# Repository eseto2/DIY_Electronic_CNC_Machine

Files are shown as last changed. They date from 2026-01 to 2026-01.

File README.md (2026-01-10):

# Introduction to DIY 3D Printed CNC Machine

## 🛠 Project Overview
This project documents the design and assembly of a low-cost, fully functional CNC machine built using **3D printed parts**, **aluminum profiles**, and **standard electronics**. It is capable of milling materials ranging from wood and MDF to acrylic and aluminum.

## ⚙️ Hardware & Electronics
The machine relies on accessible components. Below is a summary of the key parts required:

| Part | What it looks like | Amount needed |
| --- | --- | --- |
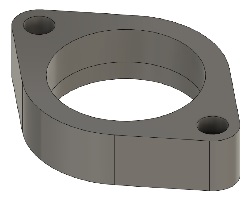
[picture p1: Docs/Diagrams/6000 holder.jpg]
6000 holder
| [6000 holder](6000%20holder.stl) |  | 3 |
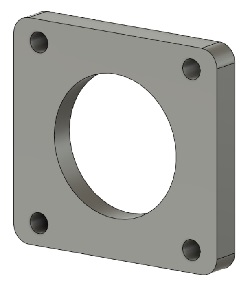
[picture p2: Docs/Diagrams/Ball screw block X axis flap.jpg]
Ball screw block X axis flap
| [Ball screw block X axis flap](Ball%20screw%20block%20X%20axis%20flap.stl) |  | 1
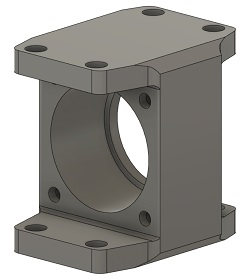
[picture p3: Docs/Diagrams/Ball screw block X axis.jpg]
Ball screw block X axis
| [Ball screw block X axis](Ball%20screw%20block%20X%20axis.stl) |  | 1
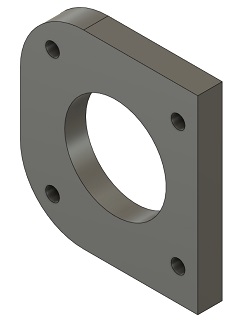
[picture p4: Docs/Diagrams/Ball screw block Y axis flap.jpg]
Ball screw block Y axis flap
| [Ball screw block Y axis flap](Ball%20screw%20block%20X%20axis%20flap.stl) |  | 2
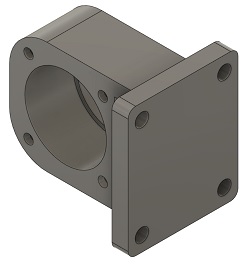
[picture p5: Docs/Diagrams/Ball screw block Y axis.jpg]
Ball screw block Y axis
| [Ball screw block Y axis](Ball%20screw%20block%20Y%20axis.stl) |  | 2
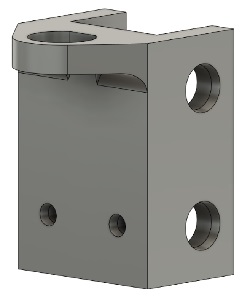
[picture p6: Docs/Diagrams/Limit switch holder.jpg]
Limit switch holder
| [Limit switch holder](Limit%20switch%20holder.stl) |  | 3
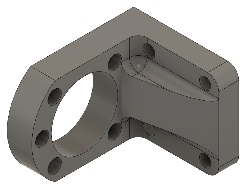
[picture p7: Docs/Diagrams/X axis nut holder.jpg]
X axis nut holder
| [X axis nut holder](X%20axis%20nut%20holder.stl) |  | 1
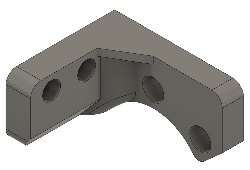
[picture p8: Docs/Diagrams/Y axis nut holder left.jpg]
Y axis nut holder left
| [Y axis nut holder left](Y%20axis%20nut%20holder%20left.stl) |  | 1
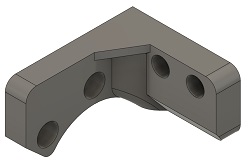
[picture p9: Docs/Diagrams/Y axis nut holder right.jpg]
Y axis nut holder right
| [Y axis nut holder right](Y%20axis%20nut%20holder%20right.stl) |  | 1
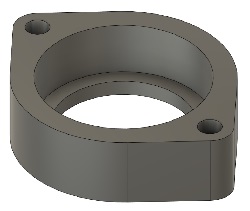
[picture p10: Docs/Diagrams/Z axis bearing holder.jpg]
Z axis bearing holder
| [Z axis bearing holder](Z%20axis%20bearing%20holder.stl) |  | 1
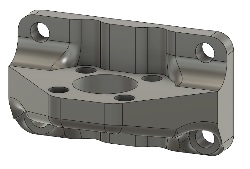
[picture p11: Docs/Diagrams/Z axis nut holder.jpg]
Z axis nut holder
| [Z axis nut holder](Z%20axis%20nut%20holder.stl) |  | 1

### Mechanical
- **Frame:** 20x20mm Aluminum Profiles (various lengths).
- **Linear Motion:** 12mm rods, Lead screws (725mm, 515mm, 160mm), and linear bearings.
- **Drive System:** GT2 timing belts and pulleys (16T & 20T).

### Electronics
- **Controller:** Arduino Uno with CNC Shield.
- **Motors:** 4x Nema 17 Stepper Motors (1.7A).
- **Drivers:** A4988 or DRV8825 stepper drivers.
- **Spindle:** 500W Spindle or 775 DC Motor.
- **Power:** 12V Power Supply (6A recommended).

## 🖨️ 3D Printing Instructions
All structural brackets and mounts are 3D printed.
- **Material:** PETG is recommended for flexibility and durability, though PLA is sufficient.
- **Infill:** 20% - 50%.
- **Perimeters:** Minimum of 5 layers (Crucial for part strength).
- **Supports:** Required for specific orientations.

## 💻 Software & Firmware
1.  **Firmware:** **GRBL** installed on the Arduino Uno.
    - *Configuration:* Set steps/mm ($100=400, etc.) via console commands.
2.  **Control Software:** **CNCjs** is recommended for sending G-code. It is open-source, cross-platform (Windows/Mac/Linux/Raspberry Pi), and has a user-friendly interface.

## 📐 Milling Settings (Reference)
Recommended starting points for different materials:

| Material | Feed Rate | Depth of Cut | Notes |
| :--- | :--- | :--- | :--- |
| **Wood / MDF** | 800 mm/min | 3 mm | Adaptive clearing recommended |
| **Acrylic** | 500 mm/min | 1 mm |
| **Aluminum** | 800 mm/min | 0.2 mm | Spindle at full speed |

## ⚠️ Safety
- **Eye Protection:** Always wear safety glasses to protect against flying chips.
- **Emergency Stop:** Install a physical kill switch or keep the software stop button accessible.
- **Hearing Protection:** Recommended for long milling sessions.
## Videos

[3D CNC Final test]

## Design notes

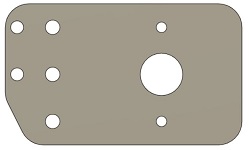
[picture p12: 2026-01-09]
Docs/Diagrams/Screw Support Left.jpg

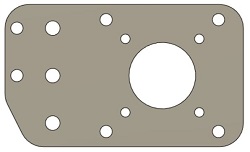
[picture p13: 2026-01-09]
Docs/Diagrams/Motor Support Left.jpg

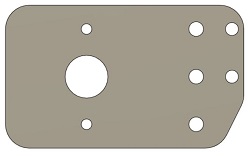
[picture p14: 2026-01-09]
Docs/Diagrams/Screw Support Right.jpg

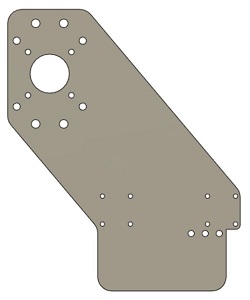
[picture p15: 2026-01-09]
Docs/Diagrams/Y Axis Left.jpg

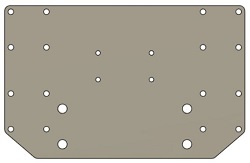
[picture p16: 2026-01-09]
Docs/Diagrams/500W Spindle Plate.jpg

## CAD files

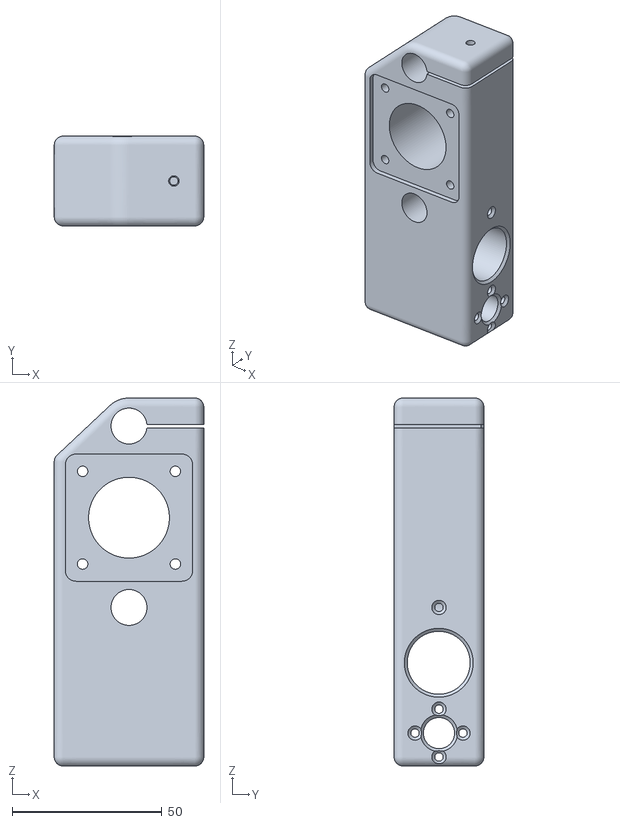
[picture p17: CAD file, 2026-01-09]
Axis_Carriage/x_axis_carriage_right.stl
50.0 x 30.0 x 123.0

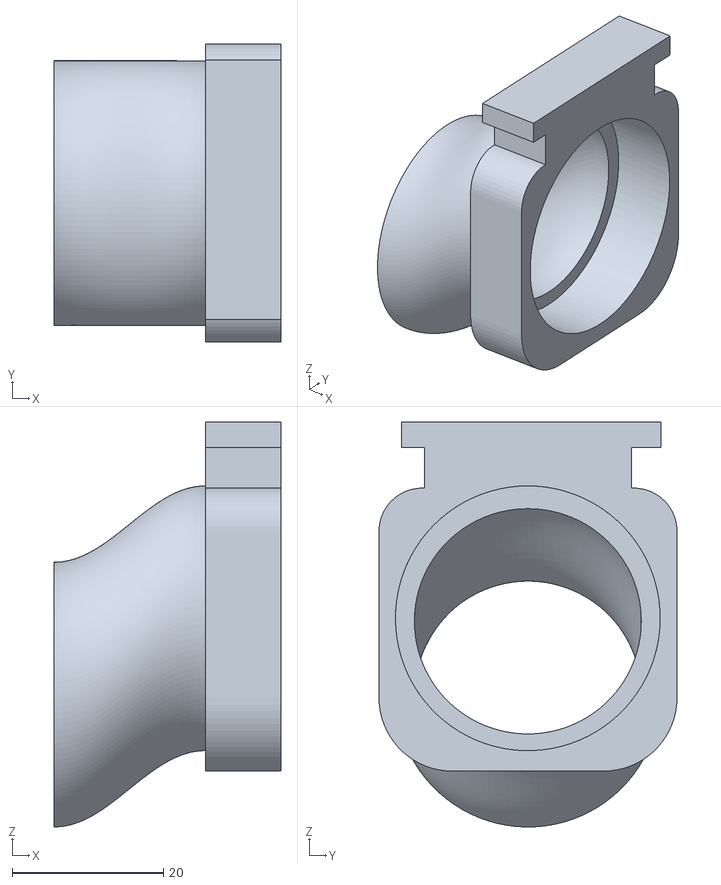
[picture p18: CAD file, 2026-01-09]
Electronics_Covers/hose connector v3.stl
30.0 x 39.4 x 53.5

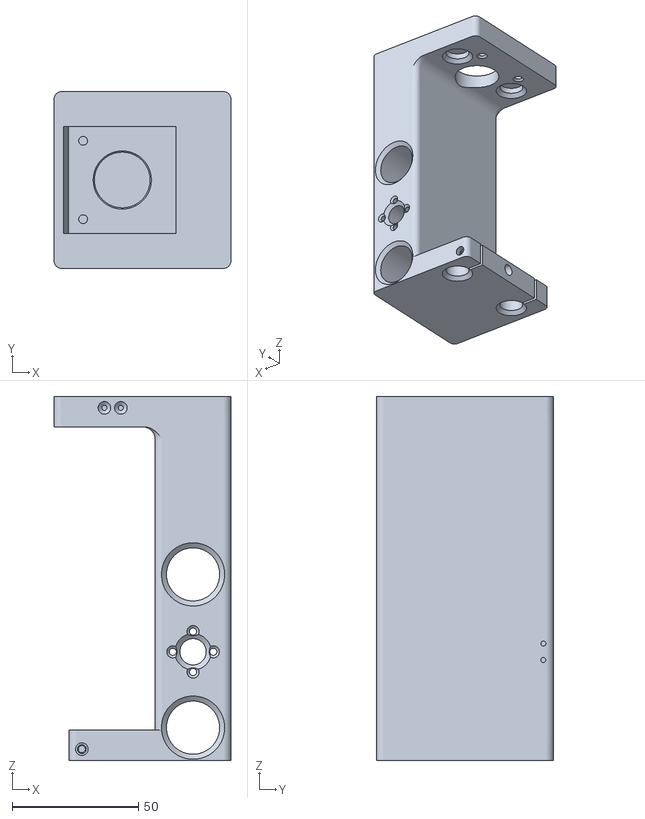
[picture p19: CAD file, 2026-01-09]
spindle_carriage.stl
70.0 x 70.0 x 144.0

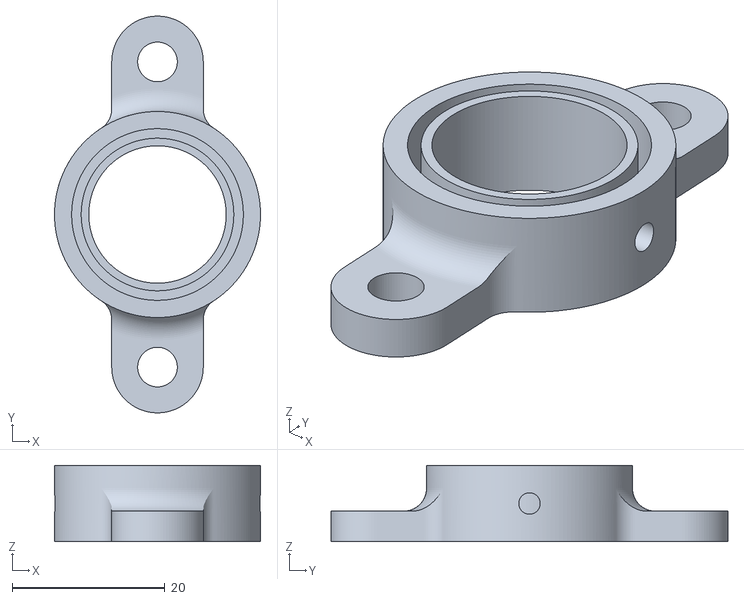
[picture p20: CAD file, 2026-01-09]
1.stl
27.0 x 52.0 x 10.0

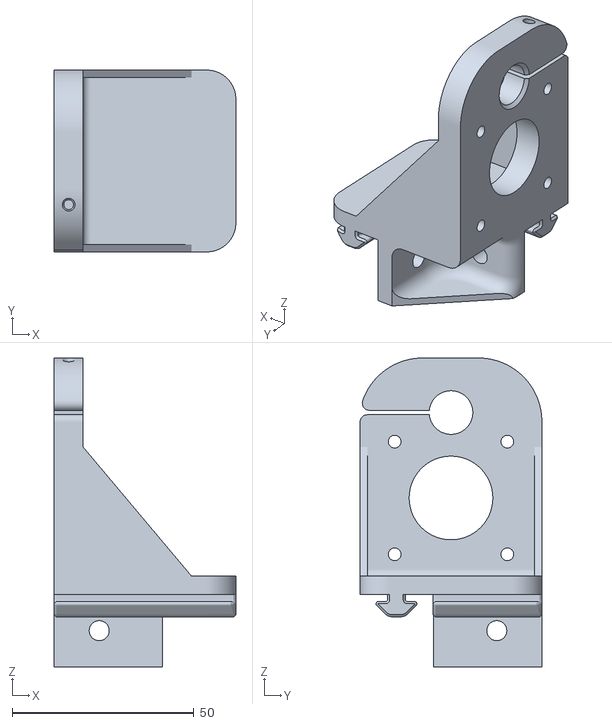
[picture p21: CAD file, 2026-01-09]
Axis_Carriage/y_axis_motor_holder_right.stl
50.0 x 50.0 x 85.0

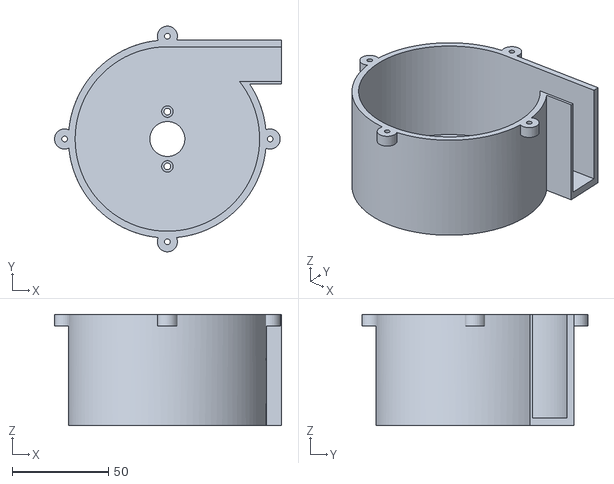
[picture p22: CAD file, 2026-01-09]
Electronics_Covers/DUst COllector Motor mount v7.stl
118.1 x 117.5 x 58.0

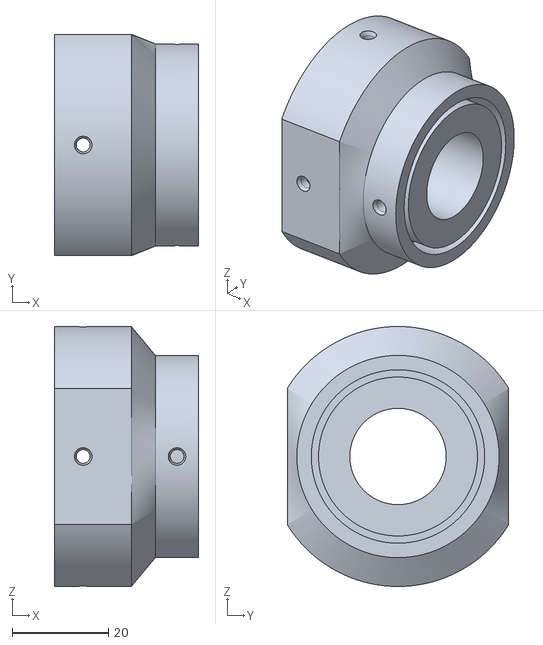
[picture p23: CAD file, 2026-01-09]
2.stl
30.0 x 46.0 x 54.0

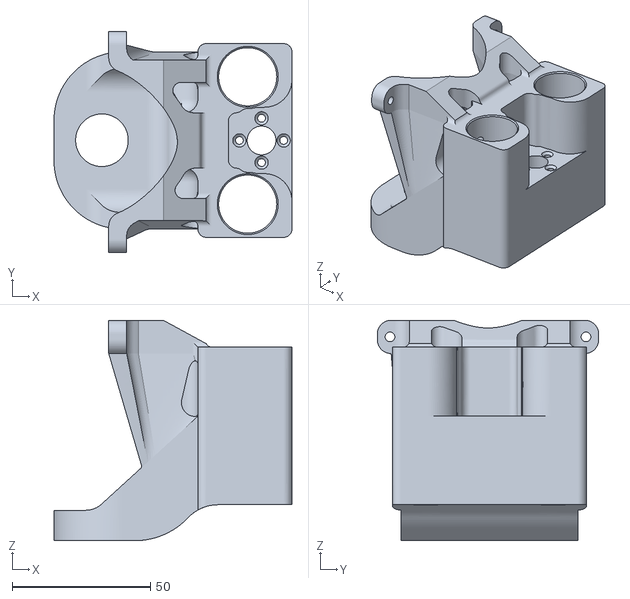
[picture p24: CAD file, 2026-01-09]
Axis_Carriage/z_axis_carriage.stl
86.0 x 80.0 x 79.6

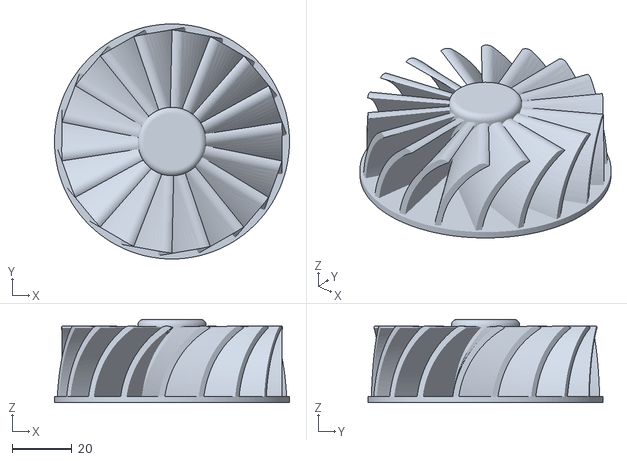
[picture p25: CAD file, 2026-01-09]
Electronics_Covers/Impeller change dirx v2.stl
79.0 x 79.0 x 28.0

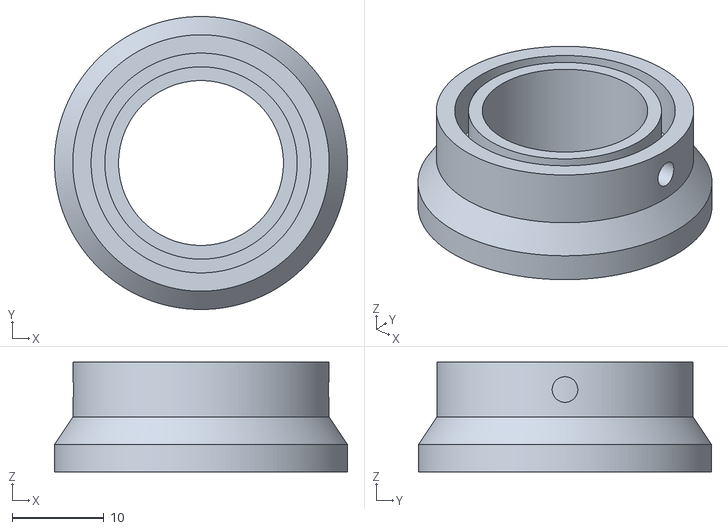
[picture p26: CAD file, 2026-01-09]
4.stl
32.0 x 32.0 x 12.0

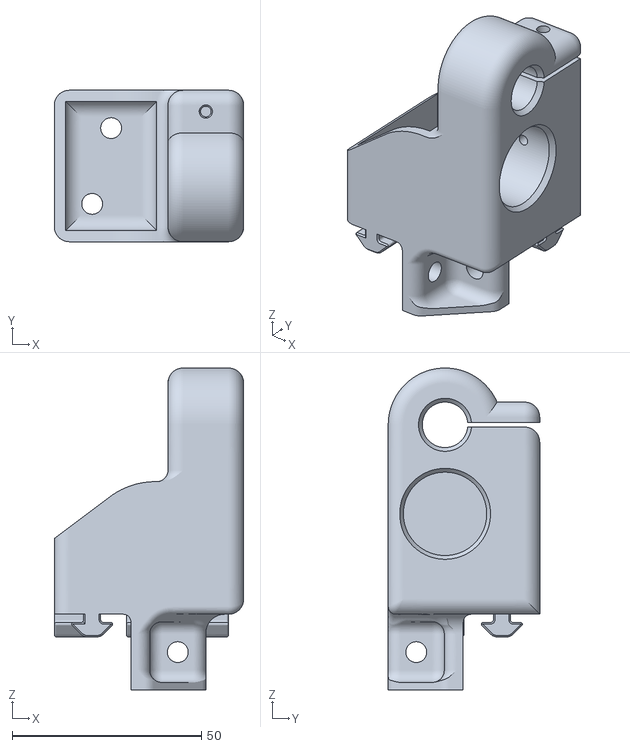
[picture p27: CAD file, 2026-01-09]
Axis_Carriage/y_axis_rod_holder_left.stl
50.0 x 40.0 x 85.0

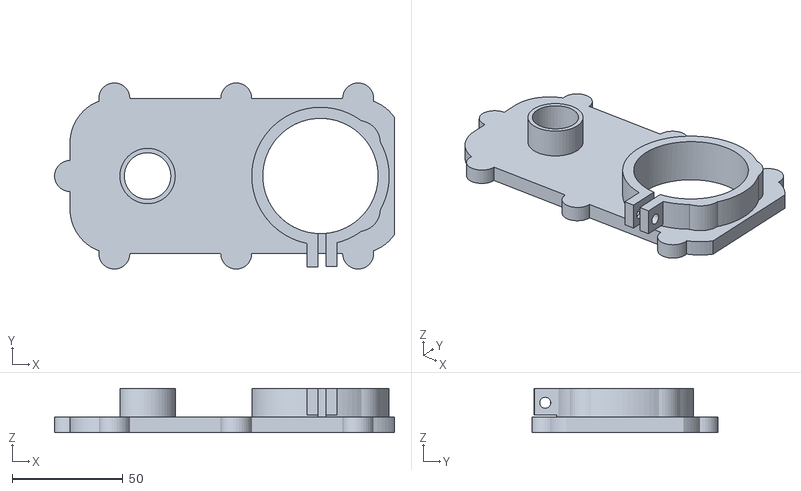
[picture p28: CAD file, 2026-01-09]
Electronics_Covers/Dust collector top v4.stl
153.4 x 84.0 x 20.0

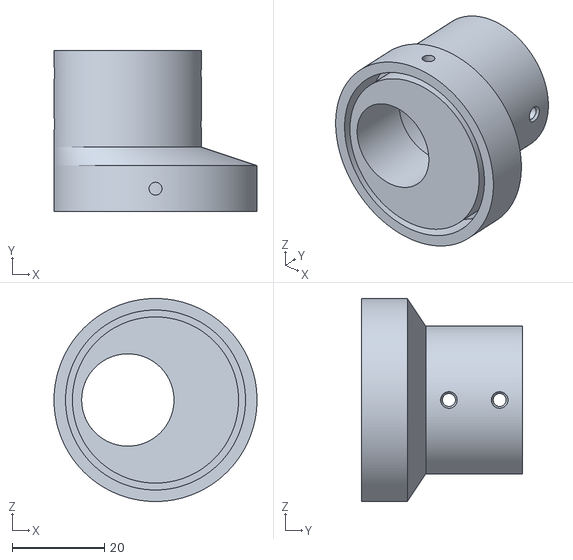
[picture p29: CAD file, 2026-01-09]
3.stl
44.0 x 35.0 x 44.0

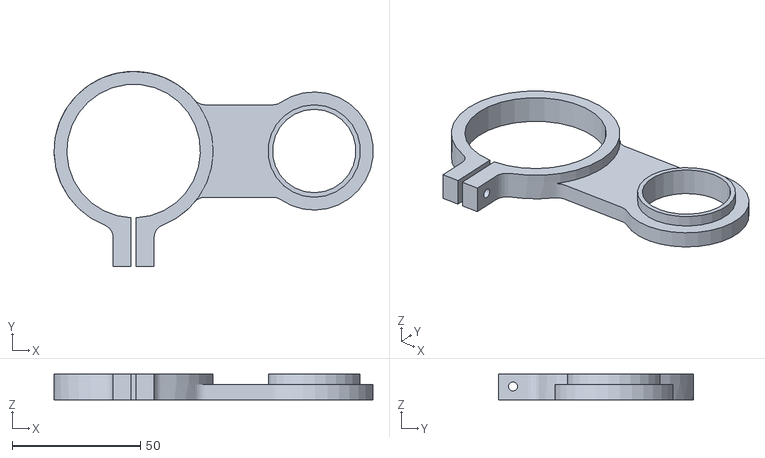
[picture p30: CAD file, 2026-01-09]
Electronics_Covers/Spindle-HoseSupport.stl
124.2 x 76.0 x 10.0

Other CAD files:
Axis_Carriage/y_axis_motor_holder_left.stl
Axis_Carriage/x_axis_carriage_left.stl
Electronics_Covers/Impeller_Quiet v2.stl
Axis_Carriage/y_axis_rod_holder_right.stl
Ball_Screw_Cover/CableChainEndAflat.stl
Ball_Screw_Cover/CableChainEndBflat.stl
Ball_Screw_Cover/CableChainLink.stl
Ball_Screw_Cover/case.stl
Ball_Screw_Cover/case_top.stl
Ball_Screw_Cover/clamp.stl
Ball_Screw_Cover/coupler.stl
Ball_Screw_Cover/cube.stl
Electronics_Covers/Cooler_Fan v1.stl
Electronics_Covers/DUst COllector Motor mount_normal v2.stl
Electronics_Covers/Dust shoe v8.stl
Electronics_Covers/Impeller v12.stl
Electronics_Covers/Laser Carriage New v10.stl
Electronics_Covers/Motor Mount v17.stl
Electronics_Covers/Spindle-HoseMount.stl
Electronics_Covers/gasket.stl
Electronics_Covers/motor_holder v2.stl
